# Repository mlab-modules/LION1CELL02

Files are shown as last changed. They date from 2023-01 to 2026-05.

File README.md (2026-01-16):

# LION1CELL02 - Single-cell Li-Ion BMS power supply with I2C interface 

LION1CELL02

Integrated battery management solution for 18650 Li-ion batteries. It can measure remaining energy in the battery, perform a charging cycle from a USB-C power source, and protect batteries against overvoltage or overdraining conditions.

## Features 

  * Charging, balancing, termination (temperature protected)
  * Gas-gauging (temperature compensated)
  * Over-voltage protection
  * Over-current protection
  * Under-voltage is not protected - the module is constructed to power the device until battery death 

## Connection

The module could communicate on the I2C or HDQ bus.

| Mark | signal| Description |
|---|-----|---|
|1 | PG |	|
|2 | STAT2 | |
|3 | GND |	|
|4 | CE | |
|5 | STAT1 | |
|6 | CMODE | |

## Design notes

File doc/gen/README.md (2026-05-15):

# PCB

Board size: N/AxN/A mm (N/AxN/A inches)

- This is the size of the rectangle that contains the board
- Thickness: 1.6 mm (63 mils)
- Material: FR4
- Finish: HAL
- Layers: 2
- Copper thickness: 35 µm

Solder mask: TOP / BOTTOM

- Color: Green

Silk screen: TOP / BOTTOM

- Color: White

# Important sizes

Clearance: 0.2 mm (8 mils)

Track width: N/A mm (N/A mils)

- By design rules: 0.0 mm (0 mils)

Drill: 0.6 mm (24 mils)

- Vias: N/A mm (N/A mils) [Design: 0.4 mm (16 mils)]
- Pads: 0.6 mm (24 mils)
- The above values are real drill sizes, they add 0.1 mm (4 mils) to plated holes (PTH)

Via: N/A/N/A mm (N/A/N/A mils)

- By design rules: 0.5/0.3 mm (20/12 mils)
- Micro via: yes [0.2/0.1 mm (8/4 mils)]
- Buried/blind via: yes
- Total: 0 (thru: 0 buried/blind: 0 micro: 0)

Outer Annular Ring: 0.15 mm (6 mils)

- By design rules: 0.15 mm (6 mils)

Eurocircuits class: 4A
- Using min drill 0.6 mm for an OAR of 0.15 mm

# General stats

Components count: (SMD/THT)

- Top: 31/7 (SMD + THT)
- Bottom: 51/4 (SMD + THT)

Defined tracks:

- 0.2 mm (8 mils)
- 0.3 mm (12 mils)
- 0.5 mm (20 mils)
- 1.0 mm (39 mils)

Used tracks:

Defined vias:

Used vias:

Holes (excluding vias):

- 0.65 mm (26 mils) (2)
- 1.0 mm (39 mils) (10)
- 1.6 mm (63 mils) (4)
- 3.0 mm (118 mils) (4)
- 3.2 mm (126 mils) (4)

Oval holes:

- 0.5x0.9 mm (20x35 mils) (2)
- 0.6x1.4 mm (24x55 mils) (2)
- 0.6x1.7 mm (24x67 mils) (2)

Drill tools (including vias and computing adjusts and rounding):

- 0.6 mm (24 mils) (2)
- 0.65 mm (26 mils) (2)
- 0.7 mm (28 mils) (4)
- 1.1 mm (43 mils) (10)
- 1.7 mm (67 mils) (4)
- 3.1 mm (122 mils) (4)
- 3.2 mm (126 mils) (4)

Solder paste stats:

Using a paste with 87.75 % alloy, that has an specific gravity for the alloy of 7.4 g/cm³
and 1.0 g/cm³ for the flux. This paste has an specific gravity of  4.15 g/cm³.

The stencil thickness is  0.12 mm.

| Side | Pads with paste | Area [mm²] | Paste [g] |
|---|---|---|---|
| Top | 59 | 67.12 | 0.33 |
| Bottom | 172 | 224.50 | 1.12 |
| Total  | 231 | 291.61 | 1.45 |

Note: this is just an approximation to the theoretical value. Margins of the solder mask and waste aren't computed.

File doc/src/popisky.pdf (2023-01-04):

List1

Stránka 1

1 – PG | 4 – CE | 1 – PG | 4 – CE | 1 – PG | 4 – CE
2 – STAT2 | 5 – STAT1 | 2 – STAT2 | 5 – STAT1 | 2 – STAT2 | 5 – STAT1
3 – GND | 6 – CMODE | 3 – GND | 6 – CMODE | 3 – GND | 6 – CMODE
1 – PG | 4 – CE | 1 – PG | 4 – CE | 1 – PG | 4 – CE
2 – STAT2 | 5 – STAT1 | 2 – STAT2 | 5 – STAT1 | 2 – STAT2 | 5 – STAT1
3 – GND | 6 – CMODE | 3 – GND | 6 – CMODE | 3 – GND | 6 – CMODE
1 – PG | 4 – CE | 1 – PG | 4 – CE | 1 – PG | 4 – CE
2 – STAT2 | 5 – STAT1 | 2 – STAT2 | 5 – STAT1 | 2 – STAT2 | 5 – STAT1
3 – GND | 6 – CMODE | 3 – GND | 6 – CMODE | 3 – GND | 6 – CMODE
1 – PG | 4 – CE | 1 – PG | 4 – CE | 1 – PG | 4 – CE
2 – STAT2 | 5 – STAT1 | 2 – STAT2 | 5 – STAT1 | 2 – STAT2 | 5 – STAT1
3 – GND | 6 – CMODE | 3 – GND | 6 – CMODE | 3 – GND | 6 – CMODE
1 – PG | 4 – CE | 1 – PG | 4 – CE | 1 – PG | 4 – CE
2 – STAT2 | 5 – STAT1 | 2 – STAT2 | 5 – STAT1 | 2 – STAT2 | 5 – STAT1
3 – GND | 6 – CMODE | 3 – GND | 6 – CMODE | 3 – GND | 6 – CMODE
1 – PG | 4 – CE | 1 – PG | 4 – CE | 1 – PG | 4 – CE
2 – STAT2 | 5 – STAT1 | 2 – STAT2 | 5 – STAT1 | 2 – STAT2 | 5 – STAT1
3 – GND | 6 – CMODE | 3 – GND | 6 – CMODE | 3 – GND | 6 – CMODE
1 – PG | 4 – CE | 1 – PG | 4 – CE | 1 – PG | 4 – CE
2 – STAT2 | 5 – STAT1 | 2 – STAT2 | 5 – STAT1 | 2 – STAT2 | 5 – STAT1
3 – GND | 6 – CMODE | 3 – GND | 6 – CMODE | 3 – GND | 6 – CMODE
1 – PG | 4 – CE | 1 – PG | 4 – CE | 1 – PG | 4 – CE
2 – STAT2 | 5 – STAT1 | 2 – STAT2 | 5 – STAT1 | 2 – STAT2 | 5 – STAT1
3 – GND | 6 – CMODE | 3 – GND | 6 – CMODE | 3 – GND | 6 – CMODE
1 – PG | 4 – CE | 1 – PG | 4 – CE | 1 – PG | 4 – CE
2 – STAT2 | 5 – STAT1 | 2 – STAT2 | 5 – STAT1 | 2 – STAT2 | 5 – STAT1
3 – GND | 6 – CMODE | 3 – GND | 6 – CMODE | 3 – GND | 6 – CMODE
1 – PG | 4 – CE | 1 – PG | 4 – CE | 1 – PG | 4 – CE
2 – STAT2 | 5 – STAT1 | 2 – STAT2 | 5 – STAT1 | 2 – STAT2 | 5 – STAT1
3 – GND | 6 – CMODE | 3 – GND | 6 – CMODE | 3 – GND | 6 – CMODE
1 – PG | 4 – CE | 1 – PG | 4 – CE | 1 – PG | 4 – CE
2 – STAT2 | 5 – STAT1 | 2 – STAT2 | 5 – STAT1 | 2 – STAT2 | 5 – STAT1
3 – GND | 6 – CMODE | 3 – GND | 6 – CMODE | 3 – GND | 6 – CMODE
1 – PG | 4 – CE | 1 – PG | 4 – CE | 1 – PG | 4 – CE
2 – STAT2 | 5 – STAT1 | 2 – STAT2 | 5 – STAT1 | 2 – STAT2 | 5 – STAT1
3 – GND | 6 – CMODE | 3 – GND | 6 – CMODE | 3 – GND | 6 – CMODE
1 – PG | 4 – CE | 1 – PG | 4 – CE | 1 – PG | 4 – CE
2 – STAT2 | 5 – STAT1 | 2 – STAT2 | 5 – STAT1 | 2 – STAT2 | 5 – STAT1
3 – GND | 6 – CMODE | 3 – GND | 6 – CMODE | 3 – GND | 6 – CMODE

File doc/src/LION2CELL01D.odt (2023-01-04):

Modul obsluhující dva sériově zapojené li-on články 18650

Jan Chroust

## Modul je osazen obvodem pro zajištění nabíjení dvou sériově zapojených li-on článků. Samozřejmostí je moderní obvod pro měření zbývající energie a celkové monitorování článků. Výstupem je I2C sběrnice. Článek je ošetřen proti případnému poškození přepětím.

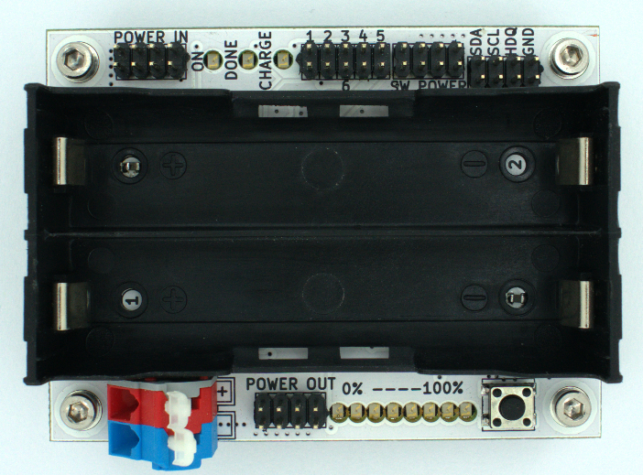
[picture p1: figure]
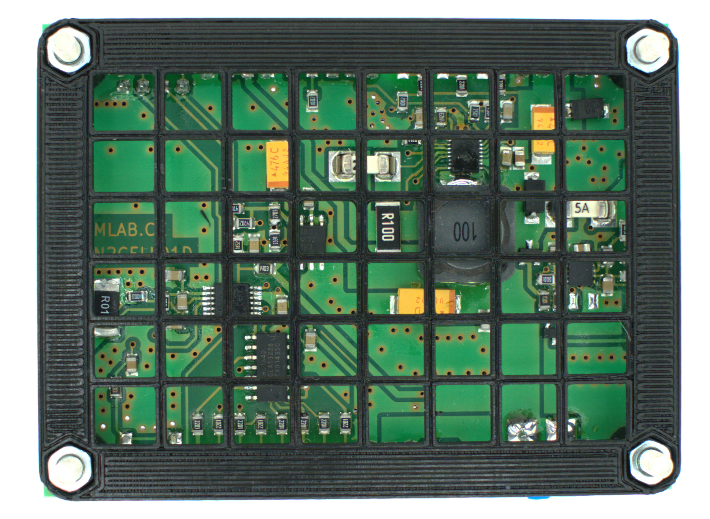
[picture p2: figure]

# Technické parametry

Parametr | Hodnota | Poznámka
Napájení | 12 V@2A | Nabíjecí proud je z výroby nastaven na cca 1,3A
Pouzdro na články | 2x18650
Rozhraní | I2C, HDQ
Integrované obvod: | BQ24103 | Nabíjení
| BQ34Z100 | Měření článku
Rozměry | 80.77 x 60.45 x 16 mm | Výška nad základní deskou

# Popis konstrukce

Modul obsahuje tři samostatné funkční celky – Dobíjecí elektroniku, měření parametrů a balanční a ochranný obvod. Většina z nich pracuje stále i když modul není využíván. Důsledkem je, že modul je nutné pravidelně nabíjet (alespoň jednou za půl roku), aby byly akumulátory udržovány v provozním rozsahu napětí.

## Nastavení děliče u BQ34Z100 pro měření napětí

Dělič pro měření napětí je tvořen odpory R23 a R24. Hodnota napětí na pinu BAT nesmí přesáhnout 900 mV, proto se hodnota odporu vypočítá následujícím vzorcem:

{R} rsub {24} =16500 Ω ( {V} rsub {in max} -900mV)/900mV

Výsledkem je pro dva články 137,5 kΩ, ale z důvodu lepší dostupnosti byl zvolen obvod R24 140kΩ. R23 16k5.

Výpočet hodnoty dělícího poměru v mV, který se zapisuje do nastavení obvodu se dopočítá tímto vzorcem:

Poměr= {1000} over {{R} rsub {23}} *( {R} rsub {23} + {R} rsub {24} )

Po vložení hodnot:

Poměr= {1000} over {16,5} *(16,5+140)

Výsledná hodnota poměru:

Poměr=9484 mV

Po převod na HEX (tato hodnota se vkládá):

Poměr=250C

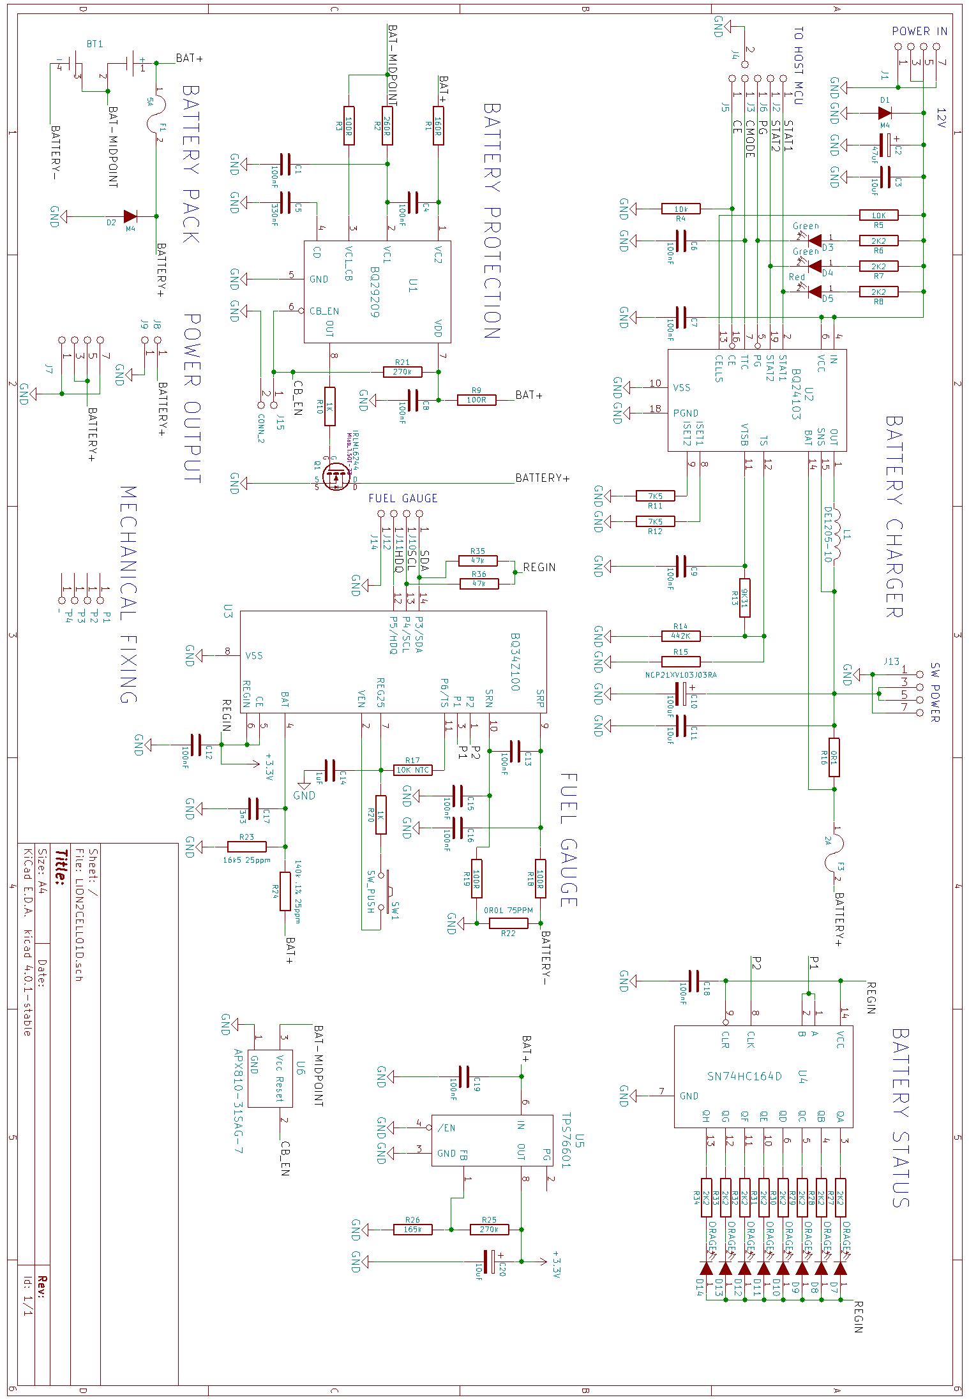
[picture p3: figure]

# Schéma

# Osazení a oživení

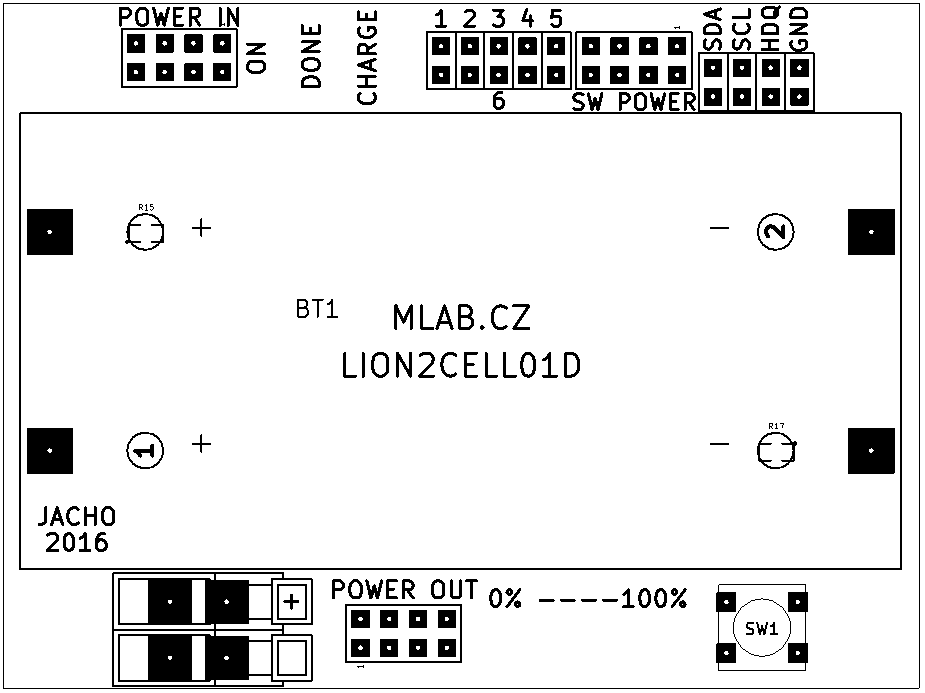
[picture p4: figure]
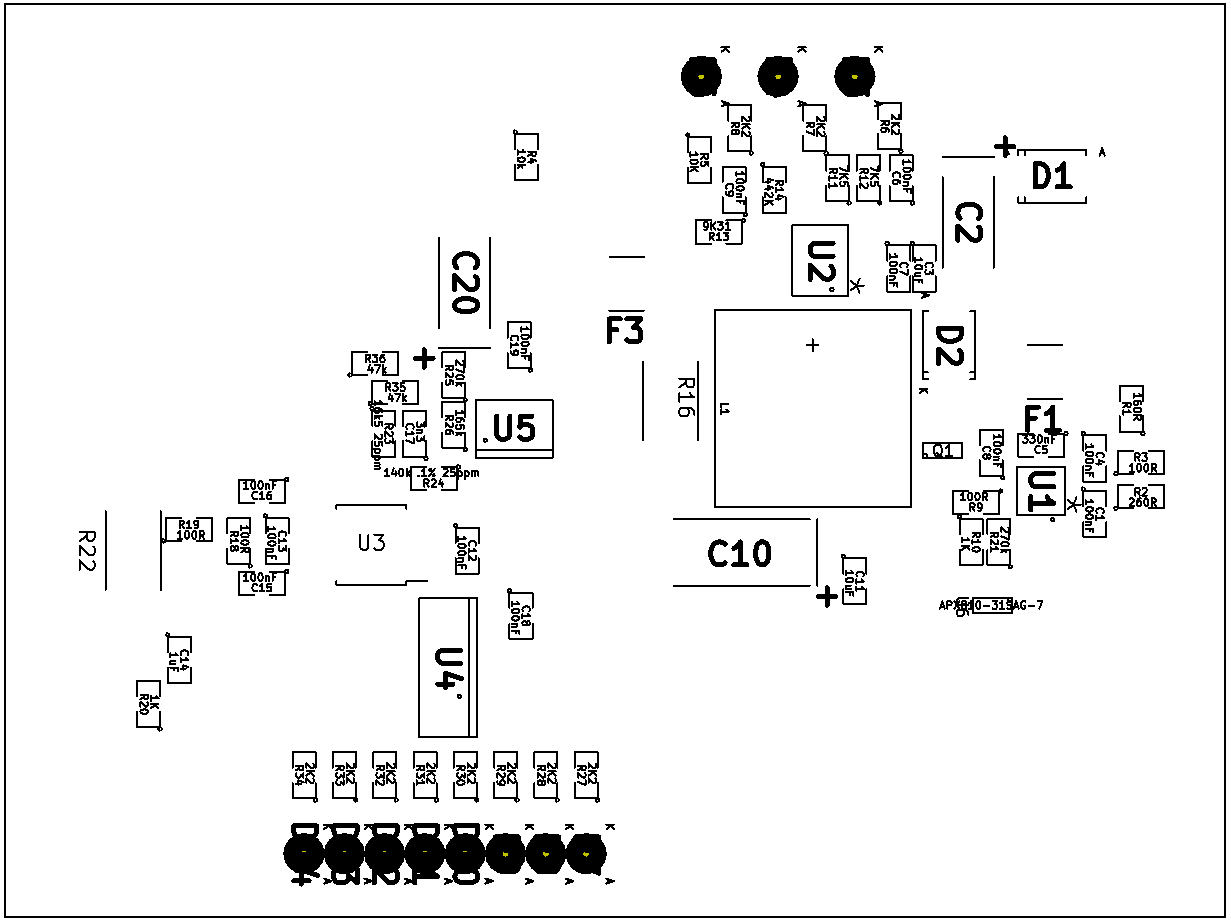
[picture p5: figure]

### Osazení

Označení | Typ | Pouzdro | Počet
BT1 | 2x18650_LION-RESCUE-LION2CELL01C | 2LION | 1
C1,C4,C6,C7,C8,C9,C12,C13,C15,C16,C18,C19 | 100nF | SMD-0805 | 12
C2 | 47uF | TantalC_SizeC_Reflow | 1
C3,C11 | 10uF | SMD-0805 | 2
C5 | 330nF | SMD-0805 | 1
C14 | 1uF | SMD-0805 | 1
C17 | 3n3 | SMD-0805 | 1
D1,D2 | M4 | SMA_Standard | 2
J1,J7,J13 | JUMP_4X2 | Straight_2x04 | 3
J2,J3,J5,J6,J10,J11,J12,J14 | JUMP_2x1 | Straight_1x02 | 8
J4 | JUMP2_2x1 | Straight_1x02 | 1
J8,J9 | CONN1_1 | WAGO256 | 2
L1 | DE1205-10 | DE1205-10 | 1
P1,P2,P3,P4 | _ | MountingHole_3mm | 4
Q1 | IRLML6244 | SOT-23 | 1
R1 | 160R | SMD-0805 | 1
R2 | 260R | SMD-0805 | 1
R3,R9,R18,R19 | 100R | SMD-0805 | 4
R4 | 10k | SMD-0805 | 1
R5 | 10K | SMD-0805 | 1
R6,R7,R8,R27,R28,R29,R30,R31,R32,R33,R34 | 2K2 | SMD-0805 | 11
R10,R20 | 1K | SMD-0805 | 2
R11,R12 | 7K5 | SMD-0805 | 2
R13 | 9K31 | SMD-0805 | 1
R14 | 442K | SMD-0805 | 1
R15 | NCP21XV103J03RA | SMD-0805 | 1
R16 | 0R1 | R_2512 | 1
R17 | 10K NTC | SMD-0805 | 1
R21,R25 | 270k | SMD-0805 | 2
R23 | 16k5 25ppm | SMD-0805 | 1
R24 | 140k .1% 25ppm | SMD-0805 | 1
R26 | 165k | SMD-0805 | 1
U4 | SN74HC164D | SO-14 | 1
SW1 | SW_PUSH | SW_PUSH_SMALL | 1
U3 | BQ34Z100 | TSSOP-14_4.4x5mm_Pitch0.65mm | 1
U1 | BQ29209 | VSON-8 | 1
C10 | 100uF | TantalC_SizeD_Reflow | 1
U2 | BQ24103 | VQFN-20 | 1
F1 | 5A | Drzak_2410 | 1
F3 | 2A | Drzak_2410 | 1
D7,D8,D9,D10,D11,D12,D13,D14 | ORAGE | LED_1206 | 8
D3,D4 | Green | LED_1206 | 2
D5 | Red | LED_1206 | 1
J15 | CONN_2 | SMD_1_2x2 | 1
C20 | 10uF | TantalC_SizeC_Reflow | 1
U5 | TPS76601 | SO-8 | 1
R35,R36 | 47k | SMD-0805 | 2
U6 | APX810-31SAG-7 | SOT-23 | 1
R22 | 0R01 75PPM | SMD-2512 | 1
Šrouby | M3x16 DIN 912 | | 4
3D tištěná podložka | | | 1

Při osazování svorkovnice J8/9, které jsou spojené do jednoho dílu je nutné uříznout přečnívající čudliky z červené části. Jinak se svorkovnice odklání od bateriového pouzdra.

3D tištěná podložka má po tisku zaslepené otvory technologickým mostem. Ten je potřeba po tisku odvrtat vrtákem o průměru 3mm. Odvrtávání je nelepší provést akušroubovákem nebo vrtačkou přepnutou na zpětný běh (tj. Opačně než by se normálně vrtákem vrtalo), tím je dosaženo přesnějšího otvoru v mostu.

### Oživení

Nejprve je dobré zkontrolovat PCB, zda je dobře zapájené. Následně se mohou vložit baterie. Je potřeba dodržet pořadí vyznačené pod pouzdrem. Nejprve se vkládá baterie do pozice 1 a pak teprve do pozice 2. Prohození pořadí může způsobit, že se modul nebude chovat správně. Po vložení posledního článku se rozsvítí oranžové LED pro diagnostiku zbývající energie článků.

Dále je vhodné vyzkoušet, zda je funkční funkce nabíjení.

Po zapojení 12V adaptéru by se měla rozsvítit zelená LED detekující připojení napájení. Následně by se měla rozsvítit červená LED indikující, že modul nabíjí. Po ukončení nabíjení druhá zelená LED indikující plně nabité akumulátory.

Program setguage2cell.py (https://github.com/mlab-modules/LION2CELL01/blob/LION2CELL01D/sw/setguage2cell.py) pro nahrání parametrů do obvodu pro měření energie článků se nachází ve složce sw (https://github.com/mlab-modules/LION2CELL01/tree/LION2CELL01D/sw) repozitáře modulu. Program používá knihovnu PyMLAB (https://github.com/MLAB-project/pymlab), kterou je potřeba mít nainstalovánu. Potom je možné modul nastavit příkazem

$ setguage2cell.py (https://github.com/mlab-modules/LION2CELL01/blob/LION2CELL01D/sw/setguage2cell.py) 8 NCR18650B

Nejsnadnější použití je pomocí modulu USBI2C01A (https://github.com/MLAB-project/Modules/tree/master/comm_serial/USBI2C01A).

Po nahrání parametrů pomocí setguage2cell.py (https://github.com/mlab-modules/LION2CELL01/blob/LION2CELL01D/sw/setguage2cell.py) je potřeba odpojit články a připojit je zpět v již popsaném pořadí. Toho lze nejsnadněji dosáhnout vražením nastříhaných plastových pásků mezi akumulátor a kontakty pouzdra. (Nastavení bez vložených akumulátorů nefunguje.)

Pro ověření, že je modul dobře zkonfigurován, slouží druhý program guage.py (https://github.com/mlab-modules/LION2CELL01/blob/LION2CELL01D/sw/guage.py), který vyčítá naměřená data.

Parametry, které se nahrávají do obvodu odpovídají článku 18650 od firmy Panasonic typ NCR18650B a nebo volitelně INR18650MJ1. V případě užití jiných akumulátorů, je potřeba nahrávané parametry změnit ve zdrojovém kódu setguage2cell.py (https://github.com/mlab-modules/LION2CELL01/blob/LION2CELL01D/sw/setguage2cell.py)! Jinak modul sice bude fungovat, ale udávaná data o kapacitě článků nebudou spolehlivá. Měření napětí na článcích, protékajícího proudu a teploty článku bude v pořádku.

Po vložení článků je potřeba provést minimálně jeden vybíjecí a nabíjecí cyklus, aby byly hodnoty zbývající energie přesnější. Čím déle budou články vloženy v modulu, tím budou měřené hodnoty přesnější. Pokud dojde k vyndání článků, tak měřící obvod resetuje měřené parametry a zpřesňování bude probíhat od začátku.

Modul je vybaven balančním obvodem, který vyrovnává napětí na obou článcích na stejnou hodnotu. Vyrovnávání se provádí tak, že jeden z článků je vybíjen. Tento vybíjecí proud měřící obvod zaznamenává. Pohybuje se řádově na hodnotě 10mA.

LION2CELL01D MLAB

LION2CELL01D / 2016-04-05 / jacho/ http://www.mlab.cz 7 / 7

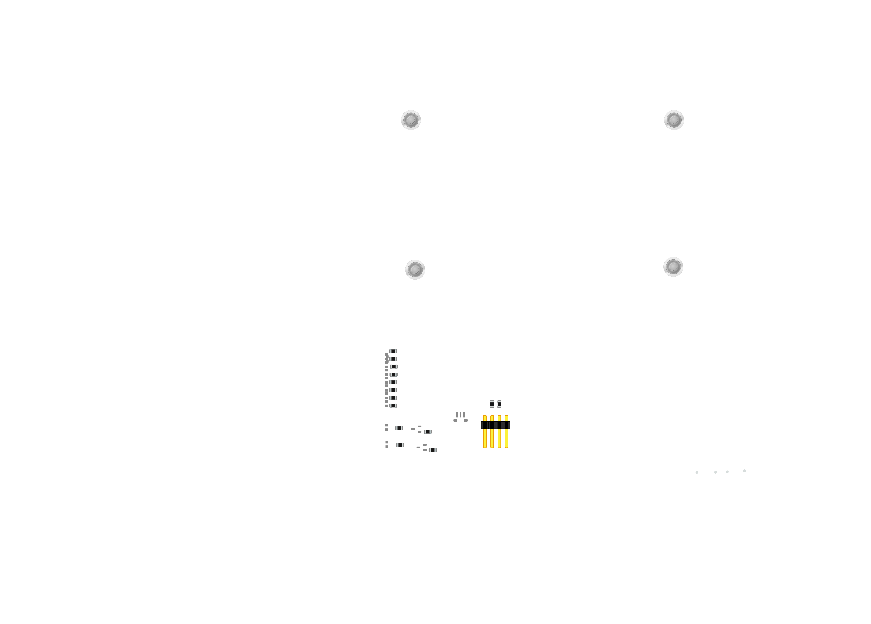
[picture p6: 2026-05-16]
doc/gen/img/LION1CELL02-top.png

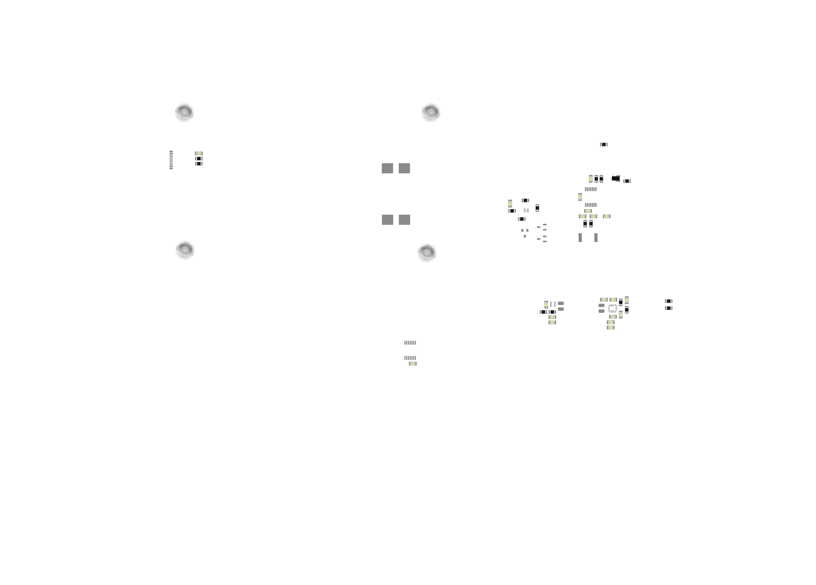
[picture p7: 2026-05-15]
doc/gen/img/LION1CELL02-bottom.png

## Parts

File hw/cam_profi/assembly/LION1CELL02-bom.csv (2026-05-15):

Component | Description | Part | References | Value | Footprint | Quantity Per PCB | Datasheet | ust_id | mfpn | mpn | sim.pins | sim.device | sim.type | i2c | height | mouser part number | mouser price/stock | manufacturer_name | manufacturer_part_number
1 | Single-cell battery | 2xBATT | BT1 | BATT | BAT_BK-18650-PC4 | 1 |  | 5c70984412875079b91f87e9
2 | Unpolarized capacitor, small symbol | C_Small | C3 | 1n | C_0805_2012Metric | 1 |  | 5c70984712875079b91f8b45 | C0805 1u | C0805 1u
3 | Unpolarized capacitor, small symbol | C_Small | C12 | 3n3 | C_0805_2012Metric | 1 |  | 5c70984712875079b91f8b47
4 | Unpolarized capacitor, small symbol | C_Small | C5 | 47n | C_0805_2012Metric | 1 |  | 65482046462c6d9e72056b98
5 | Unpolarized capacitor, small symbol | C_Small | C1C2C4C11C14C18C19 | 100n | C_0805_2012Metric | 7 |  | 5c70984712875079b91f8b4c
6 | Unpolarized capacitor, small symbol | C_Small | C8C13 | 1u | C_0805_2012Metric | 2 |  | 5c70984712875079b91f8b50
7 | Unpolarized capacitor, small symbol | C_Small | C9 | 4u7 | C_0805_2012Metric | 1 |  | 5c70984712875079b91f8b52
8 | Unpolarized capacitor, small symbol | C_Small | C7C10C17 | 10u | C_0805_2012Metric | 3 |  | 5c70984712875079b91f8b53
9 | Unpolarized capacitor, small symbol | C_Small | C6C15 | 22u | C_0805_2012Metric | 2 |  | 650b58f1462c6d9e7205463b
10 | Unpolarized capacitor, small symbol | C_Small | C16 | 47u | C_0805_2012Metric | 1 |  | 5c70984812875079b91f8bbf
11 | Dual diode, common cathode on pin 3 | D_Dual_CommonCathode_AAK | D11 | BAT54C | SOT-23 | 1
12 | Light emitting diode, small symbol | LED_Small | D5D6D7D8D10 | GREEN | SMD_LED_RIGHT_KINGBRIGHT_1605 | 5 |  | 65481f0c462c6d9e72056b3d |  |  | 1=K 2=A
13 | Light emitting diode, small symbol | LED_Small | D3D4D9 | ORANGE | SMD_LED_RIGHT_KINGBRIGHT_1605 | 3 |  | 65481fdd462c6d9e72056b6a |  |  | 1=K 2=A
14 | Light emitting diode, small symbol | LED_Small | D1D2 | RED | SMD_LED_RIGHT_KINGBRIGHT_1605 | 2 |  | 65481f96462c6d9e72056b54 |  |  | 1=K 2=A
15 | Fuse | Fuse | F1F2 | Fuse | Fuseholder_Littelfuse_Nano2_154x | 2 |  | 5c70984512875079b91f88d8
16 | 1x04 2.54 mm pitch header | HEADER_1x04 | J3 | HEADER_1x04 | PinHeader_1x04_P2.54mm_Horizontal | 1
17 | 2x03 2.54 mm pitch header | HEADER_2x03 | J2 | HEADER_2x03 | PinHeader_2x03_P2.54mm_Vertical | 1
18 | USB 2.0-only Type-C Receptacle connector | USBC_USB4105-GF-A | J1 | USBC_USB4105-GF-A | USBC GCT_USB4105-GF-A | 1 |  | 5fa0f94612875025b397795e | USB4105-GF-A | USB4105-GF-A
19 | Inductor | L | L1L2 | 1uH - DFE252012P-1R0M=P2 | L_1008_2520Metric | 2 |  | 650b5977462c6d9e72054656
20 | N-MOSFET transistor, gate/drain/source | Q_NMOS_GDS | Q4Q5 | AO3400A | SOT-23-3 | 2
21 | PNP transistor, base/emitter/collector | Q_PNP_BEC | Q2Q3 | BC807-25 | SOT-23-3 | 2 |  | 5c70984712875079b91f8aeb |  |  | 1=C 2=B 3=E | NPN | GUMMELPOON
22 | P-MOSFET transistor, gate/source/drain | Q_PMOS_GSD | Q1 | BSS83P | SOT-23 | 1 |  | 5c70984712875079b91f8ae6
23 | Resistor, small symbol | R_Small | R17R18R19R20R24 | 68R | R_0805_2012Metric | 5 |  | 5c70984512875079b91f8975
24 | Resistor, small symbol | R_Small | R1R4 | 100R | R_0805_2012Metric | 2 |  | 5c70984512875079b91f8977
25 | Resistor, small symbol | R_Small | R11R13R14R15R16R23 | 270R | R_0805_2012Metric | 6 |  | 5c70984512875079b91f8983
26 | Resistor, small symbol | R_Small | R25 | 330 | R_0805_2012Metric | 1
27 | Resistor, small symbol | R_Small | R10 | 510R | R_0805_2012Metric | 1 |  | 5c70984512875079b91f8988
28 | Resistor, small symbol | R_Small | R12R21R22R28R29 | 1k | R_0805_2012Metric | 5 |  | 5c70984512875079b91f898c
29 | Resistor, small symbol | R_Small | R27 | 2k2 | R_0805_2012Metric | 1
30 | Resistor, small symbol | R_Small | R7 | 2k4 | R_0805_2012Metric | 1 |  | 5c70984612875079b91f8991
31 | Resistor, small symbol | R_Small | R30R31 | 4k7 | R_0805_2012Metric | 2 |  | 5c70984512875079b91f898c
32 | Resistor, small symbol | R_Small | R2R3R5 | 5k1 | R_0805_2012Metric | 3 |  | 5fa0fc3e12875025b3977997
33 | Resistor, small symbol | R_Small | R6 | 33k | R_0805_2012Metric | 1 |  | 5c70984712875079b91f8a8a
34 | Resistor, small symbol | R_Small | R9 | 91k | R_0805_2012Metric | 1 |  | 5c70984712875079b91f8a95
35 | Resistor, small symbol | R_Small | R8 | 511k | R_0805_2012Metric | 1 |  | 650b5a43462c6d9e7205468e
36 | Resistor, small symbol | R_Small | R26 | 0R01 75PPM | R_2512_6332Metric | 1 |  | 5c70984712875079b91f8abf
37 | Push button switch, generic, two pins | SW_Push_shield | SW1 | SKRTLAE010 | SKRT | 1
38 | Temperature dependent resistor | Thermistor | TH1 | 10k NTC | R_0805_2012Metric | 1 |  | 5c70984712875079b91f8ac5
39 | Temperature dependent resistor, negative temperature coefficient | Thermistor_NTC | TH2 | 10k NTC | R_0805_2012Metric | 1 |  | 5c70984712875079b91f8ac5
40 | BQ25628E I2C Controlled 1-Cell, 2-A, Maximum 18-V Input, Buck Battery Charger withNVDC Power Path Management | BQ25628E | U2 | BQ25628E | Texas_S-WQFN-HR-18 | 1 | https://www.ti.com/lit/ds/symlink/bq25628e.pdf | 65481a71462c6d9e72056aa4 |  |  |  |  |  | 0x6B
41 | Voltage and Current Protection for Single-Cell Li-Ion and Li-Polymer Batteries | BQ297xy | U5 | BQ29700DSER | WSON-6_1.5x1.5mm_P0.5mm | 1 | http://www.ti.com/lit/ds/symlink/bq2970.pdf
42 |  | BQ34Z100 | U1 | BQ34Z100 | TSSOP-14_4.4x5mm_Pitch0.65mm | 1 | https://www.ti.com/lit/ds/symlink/bq34z100-g1.pdf | 5c70984612875079b91f89c3 |  |  |  |  |  | 0xAA | 1,2
43 |  | SN74HC164D | U4 | SN74HC164P | TSSOP-14_4.4x5mm_P0.65mm | 1 | https://www.ti.com/lit/ds/symlink/sn74hc164.pdf | 6559399f95a79cc5ac40a0a6
44 | Switching Voltage Regulators 1.5-A output current, high power density buck-boost converter | TPS631000DRLR | U3 | TPS631000DRLR | SOT-583-8 | 1 | https://www.ti.com/lit/ds/symlink/tps631000.pdf?ts=1652152702265 | 63de5ae4ae0b2d5aa05e2714 |  |  |  |  |  |  | 0.5 | 595-TPS631000DRLR | https://www.mouser.co.uk/ProductDetail/Texas-Instruments/TPS631000DRLR?qs=rSMjJ%252B1ewcRYwoN2deTeNA%3D%3D | Texas Instruments | TPS631000DRLR

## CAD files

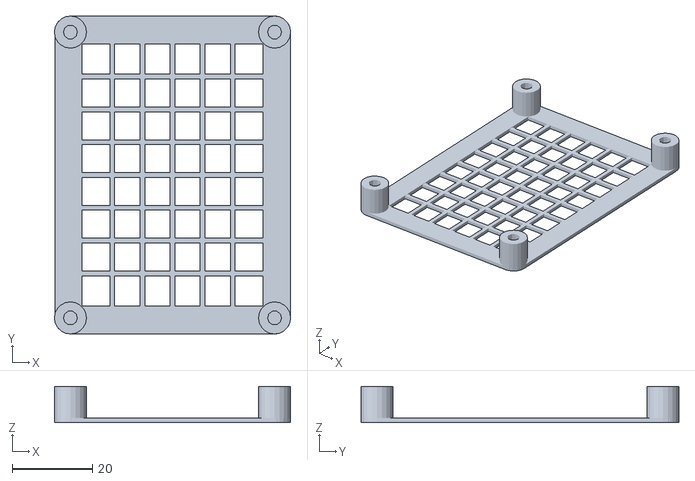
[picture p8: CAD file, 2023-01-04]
cad/6x8MLAB_frame.stl
58.8 x 79.1 x 9.00

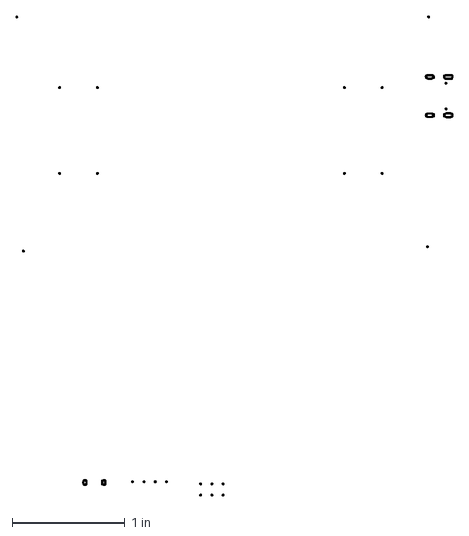
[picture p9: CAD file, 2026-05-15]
doc/gen/dxf/LION1CELL02-User_Drawings.dxf
3.87 x 4.25 in

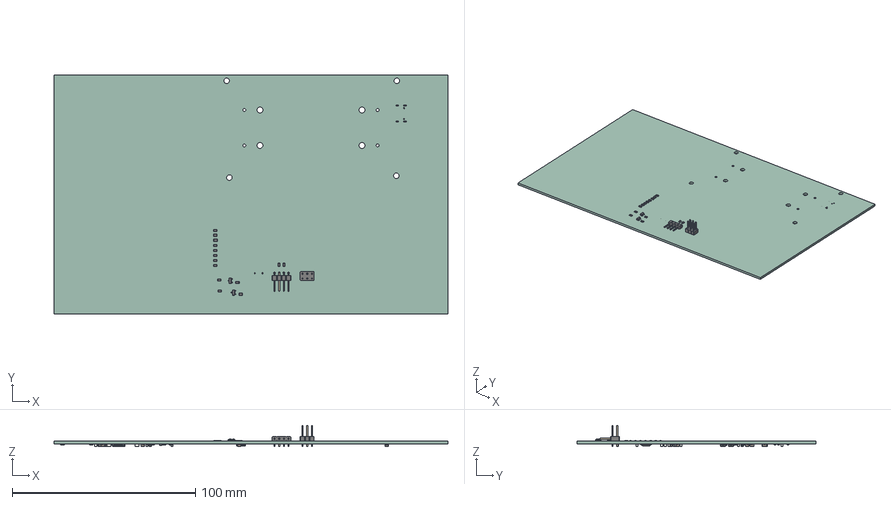
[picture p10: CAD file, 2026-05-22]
doc/gen/LION1CELL02.step
214.7 x 130.0 x 11.5 mm
SOT-23-3 x 4
R_0805_2012Metric x 32
PinHeader_2x03_P2.54mm_Vertical
PinHeader_1x04_P2.54mm_Horizontal
L_1008_2520Metric x 2
SOT-583-8
R_2512_6332Metric
C_0805_2012Metric x 18
Texas_S-PWQFN-N20
SOT-23
TSSOP-14_4.4x5mm_P0.65mm
WSON-6_1.5x1.5mm_P0.5mm
kibot_98wqftvz_PCB

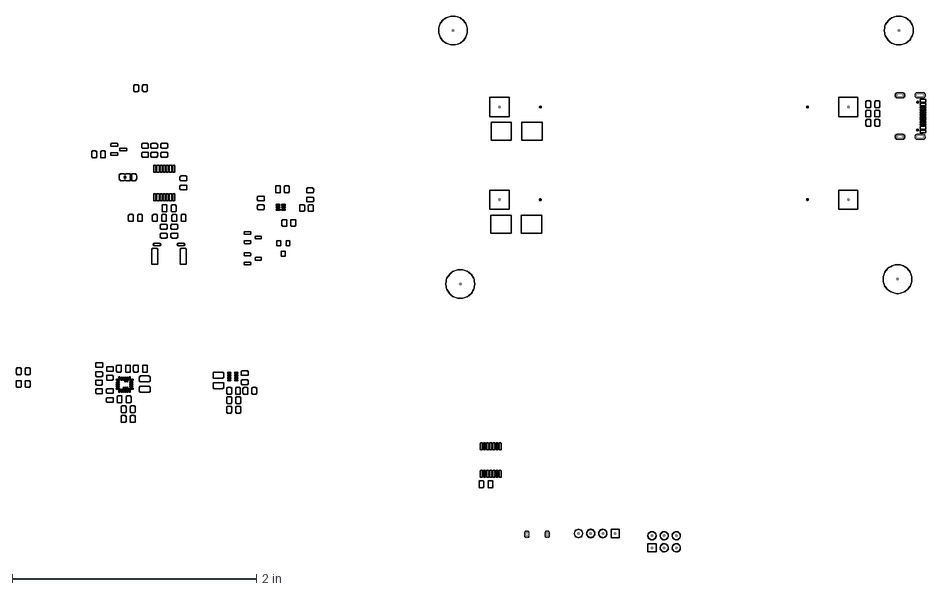
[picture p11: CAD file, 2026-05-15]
doc/gen/dxf/LION1CELL02-B_Cu.dxf
7.45 x 4.39 in

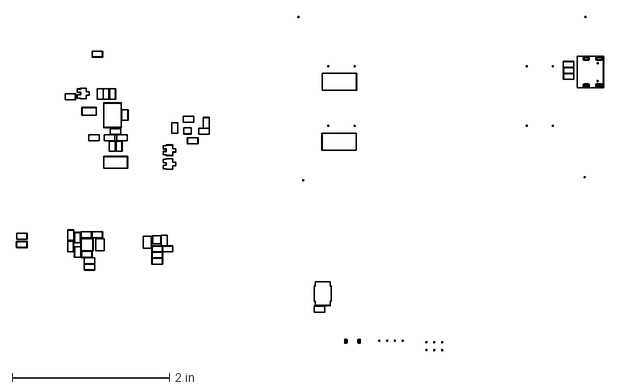
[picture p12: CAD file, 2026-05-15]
doc/gen/dxf/LION1CELL02-B_Courtyard.dxf
7.47 x 4.25 in

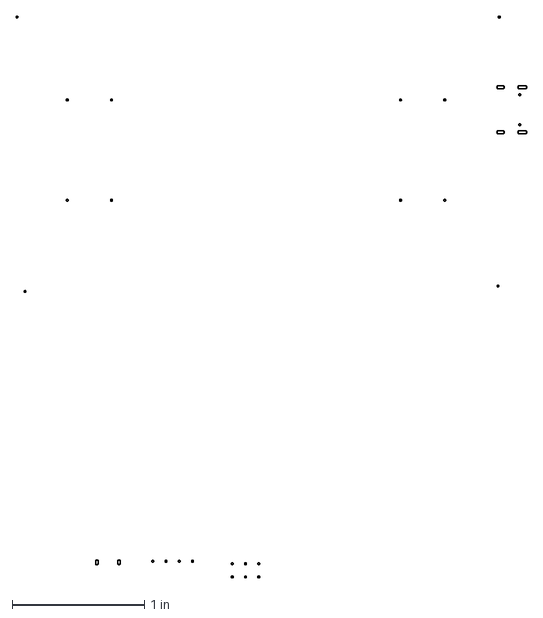
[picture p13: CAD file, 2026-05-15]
doc/gen/dxf/LION1CELL02-B_Adhesive.dxf
3.87 x 4.25 in

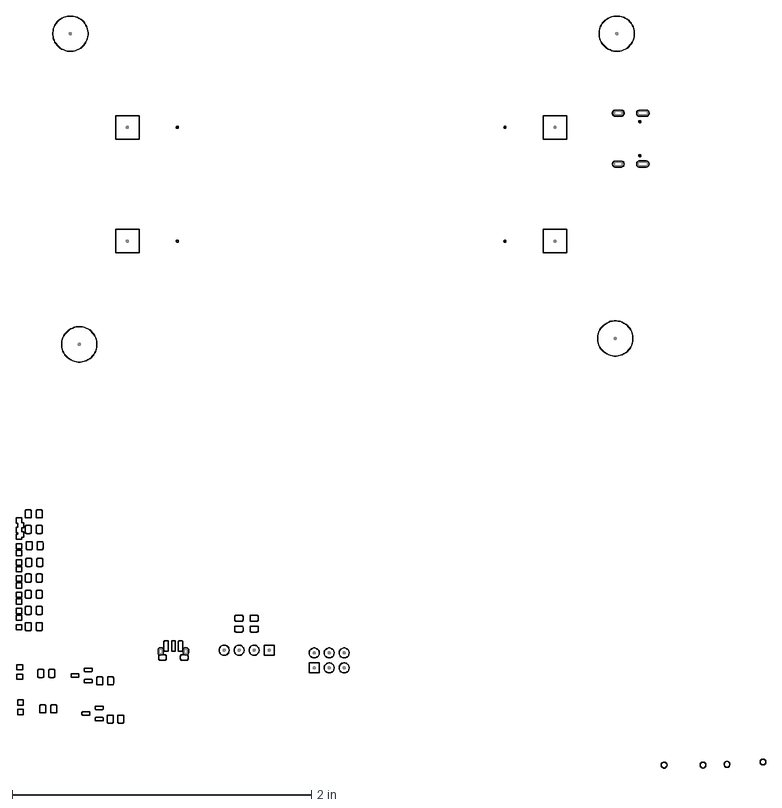
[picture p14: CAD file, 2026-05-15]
doc/gen/dxf/LION1CELL02-F_Cu.dxf
5.01 x 5.03 in

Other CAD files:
cad/src/6x8MLAB_frame.scad
doc/gen/dxf/LION1CELL02-B_Fab.dxf
doc/gen/dxf/LION1CELL02-B_Mask.dxf
doc/gen/dxf/LION1CELL02-B_Paste.dxf
doc/gen/dxf/LION1CELL02-B_Silkscreen.dxf
doc/gen/dxf/LION1CELL02-F_Courtyard.dxf
doc/gen/dxf/LION1CELL02-F_Fab.dxf
doc/gen/dxf/LION1CELL02-F_Mask.dxf
doc/gen/dxf/LION1CELL02-F_Paste.dxf
doc/gen/dxf/LION1CELL02-F_Silkscreen.dxf
doc/gen/dxf/LION2CELL01D-F_Courtyard.dxf
doc/gen/dxf/LION2CELL01D-F_Fab.dxf
doc/gen/dxf/LION2CELL01D-Margin.dxf
doc/gen/dxf/LION2CELL01D-User_Drawings.dxf
doc/gen/dxf/LION2CELL01D-User_Eco1.dxf
doc/gen/dxf/LION2CELL01D-User_Eco2.dxf

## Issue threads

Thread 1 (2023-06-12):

Output voltage converter

kaklik, 2023-06-12:
Vypadá to že pro aktualizovanou verzi modulu je vhodný měnič [TPS631000](https://www.ti.com/product/TPS631000).

_Originally posted by @kaklik in https://github.com/mlab-modules/LION1CELL01/issues/1#issuecomment-1365806545_

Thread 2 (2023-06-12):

Add USB-C connector for charging

kaklik, 2023-06-12:
Moderní řešení jak něco nabíjet je připojit zařízení přes USB-C. Tudíž by se hodil USB-C nabíjecí konektor.

To ale znamená vyměnit aktuální dobíjecí obvod za nějaký který umí [power delivery](https://www.alza.cz/usb-power-delivery) pro nabíjení lion-akumulátorů.

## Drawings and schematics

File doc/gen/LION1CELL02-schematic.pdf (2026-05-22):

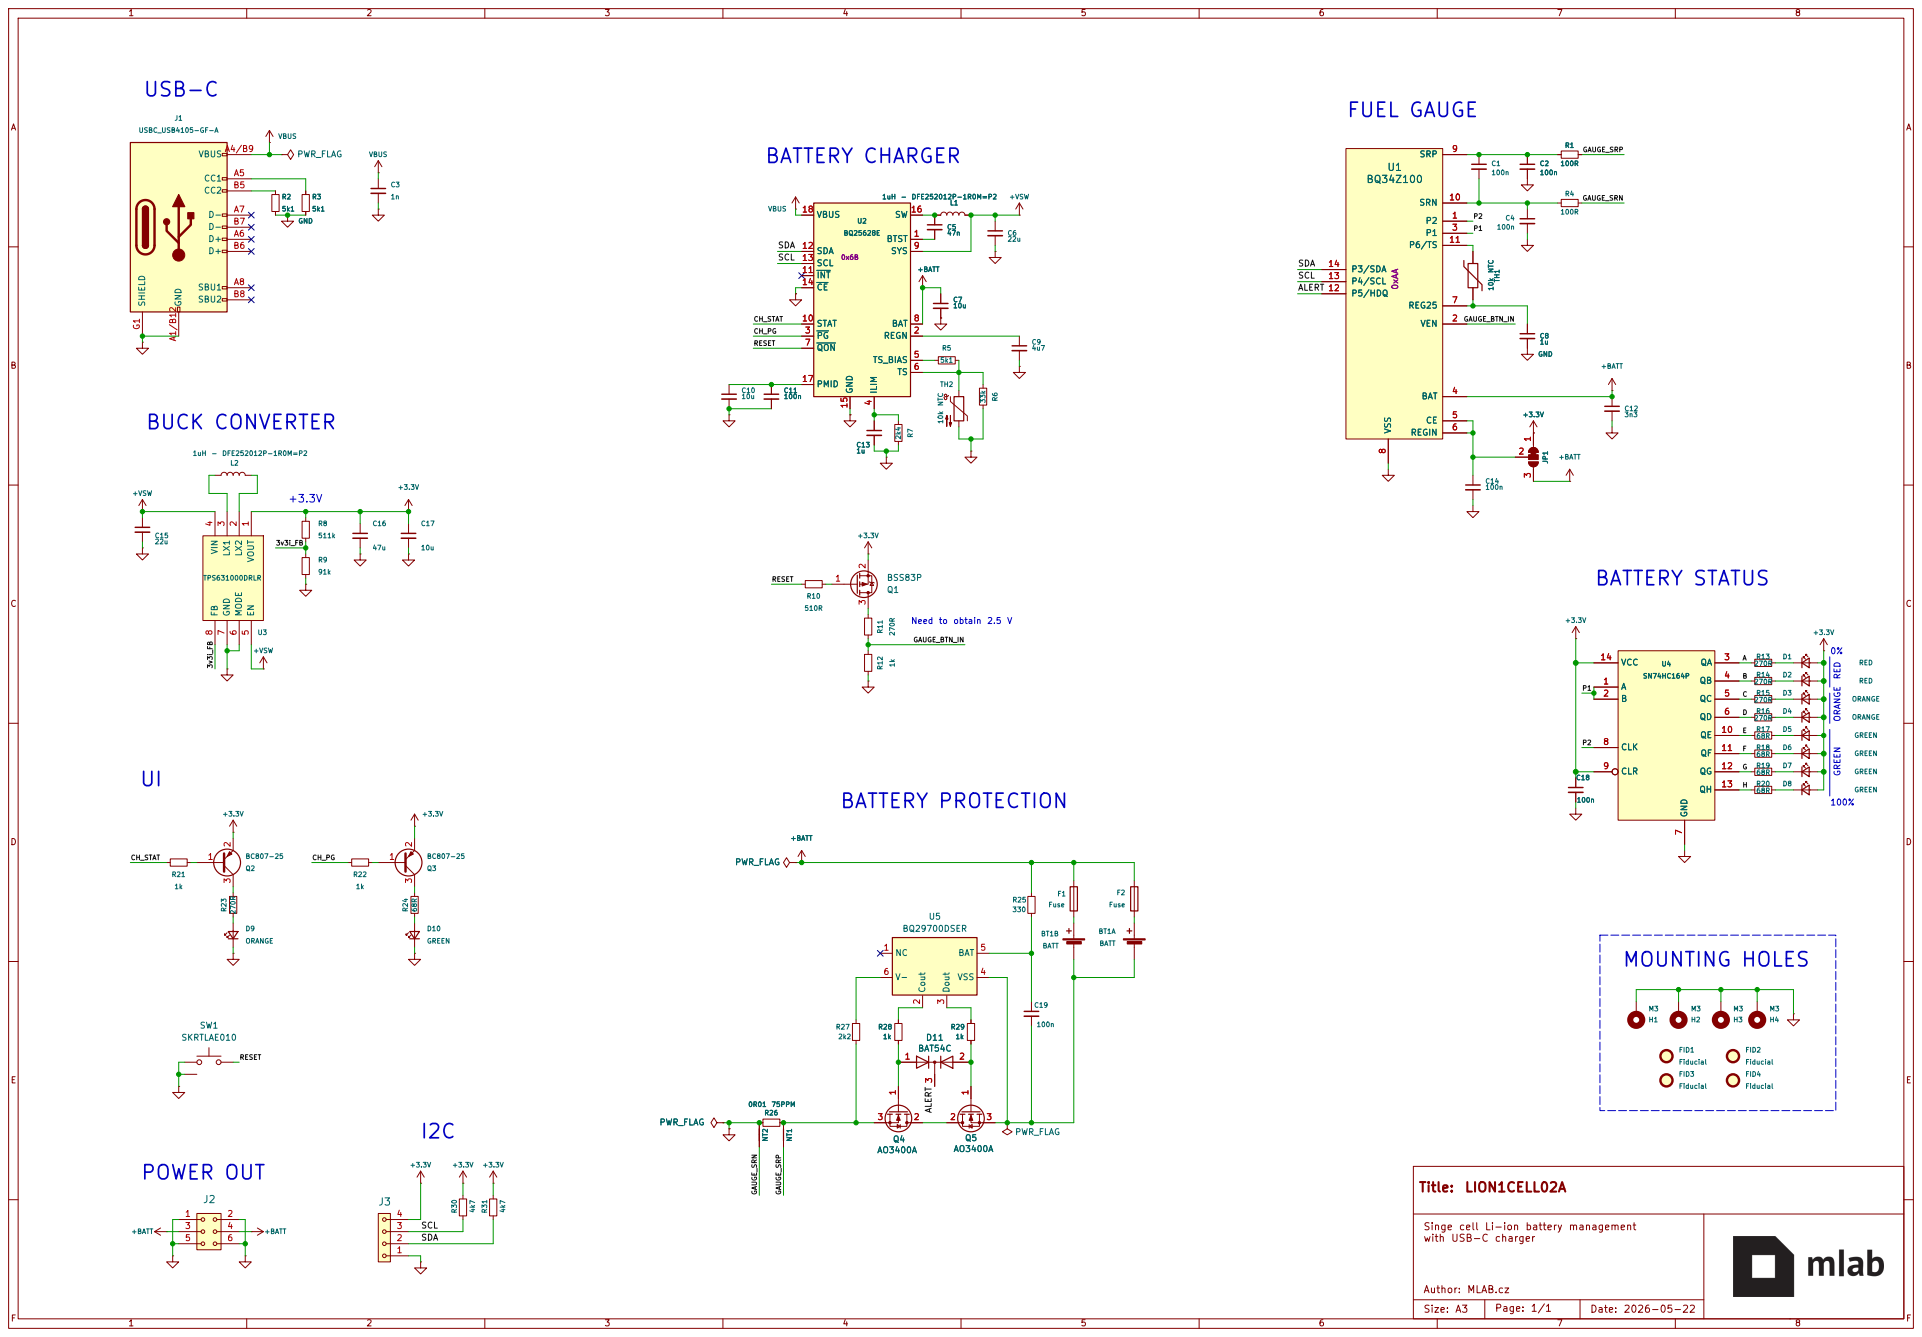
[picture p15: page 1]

Need to obtain 2.5 V BATTERY CHARGER

Singe cell Li-ion battery management

Size: A3 | Page: 1/1 | Date: 2026-05-22

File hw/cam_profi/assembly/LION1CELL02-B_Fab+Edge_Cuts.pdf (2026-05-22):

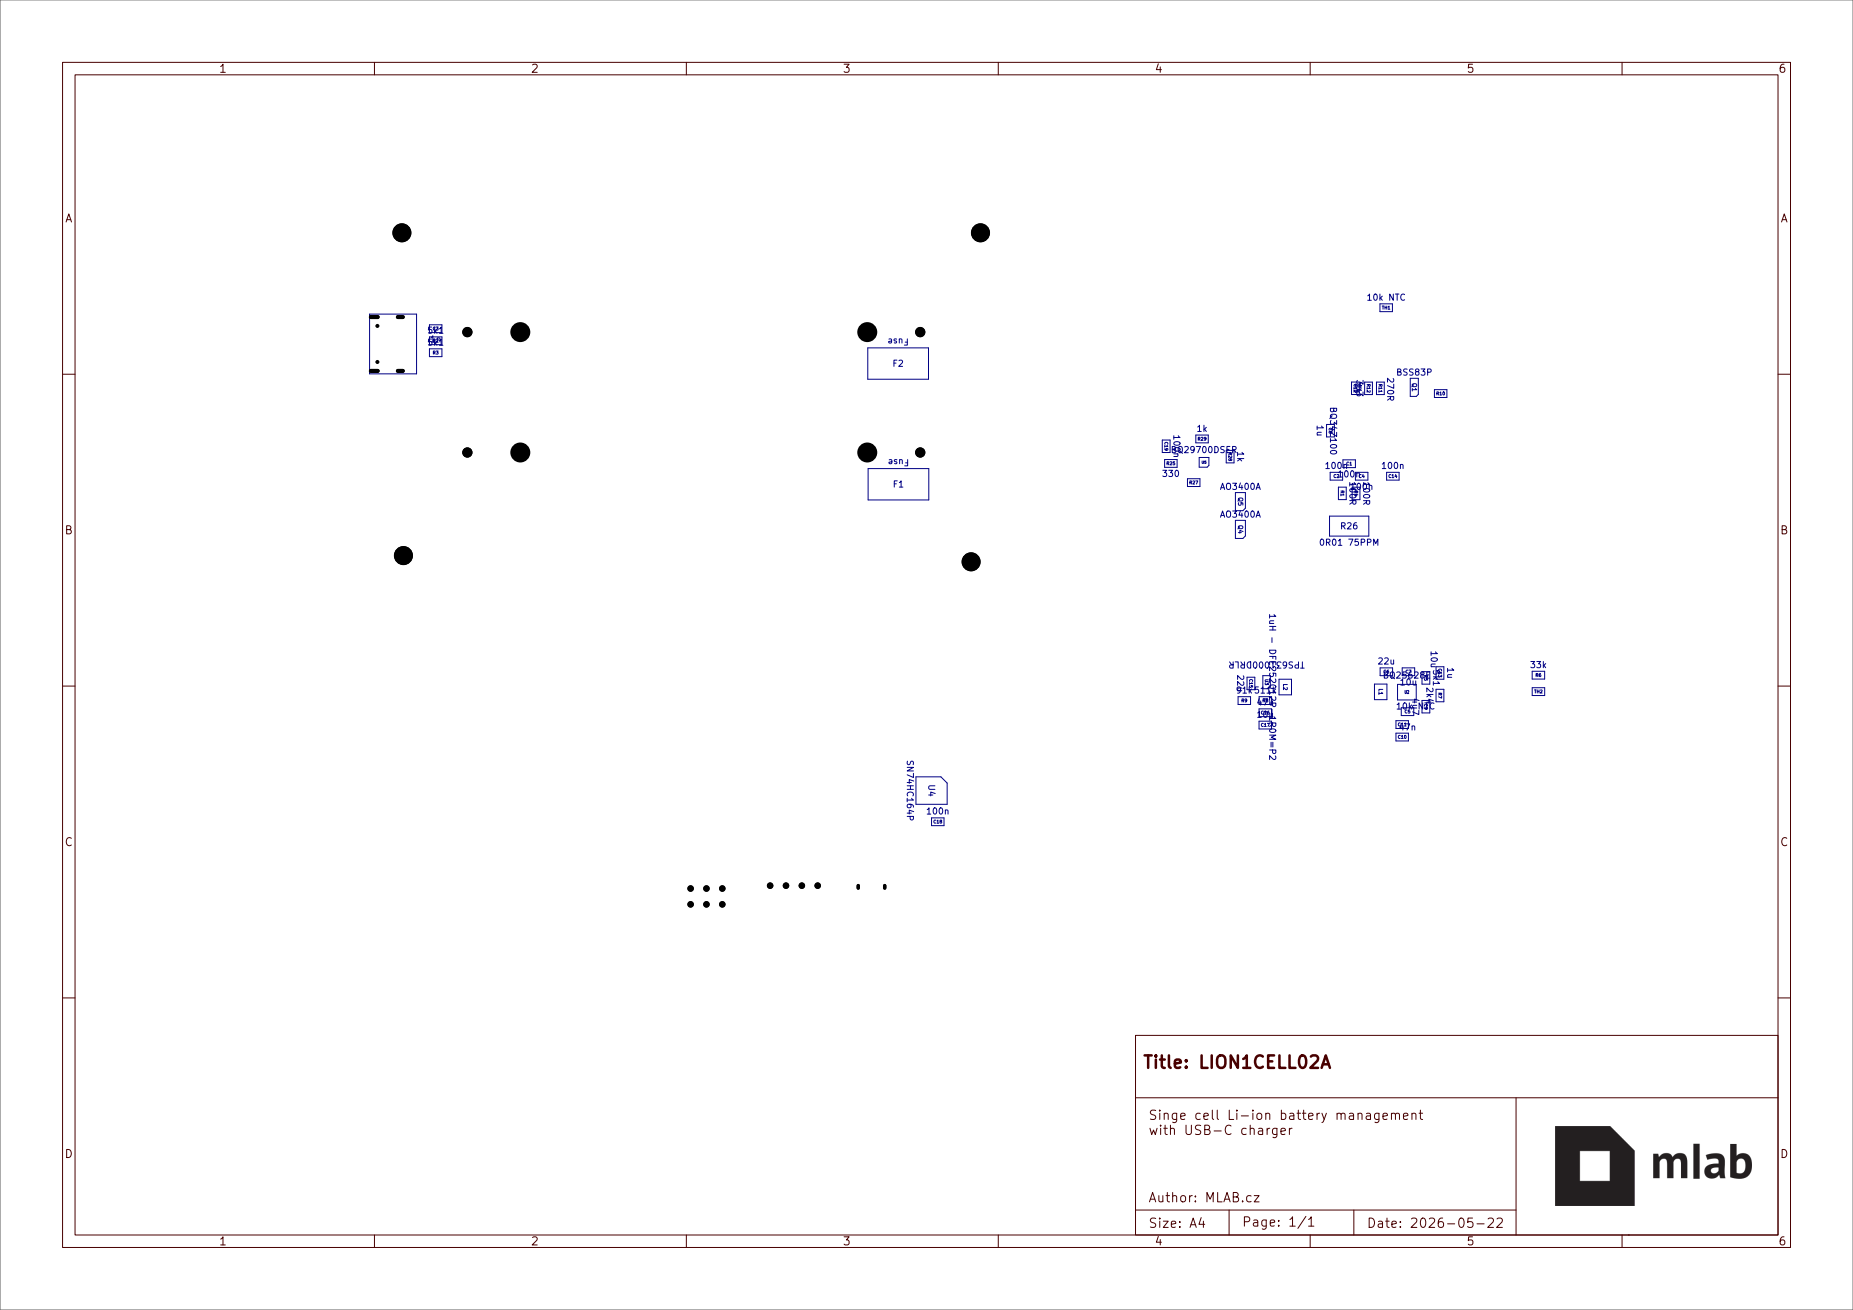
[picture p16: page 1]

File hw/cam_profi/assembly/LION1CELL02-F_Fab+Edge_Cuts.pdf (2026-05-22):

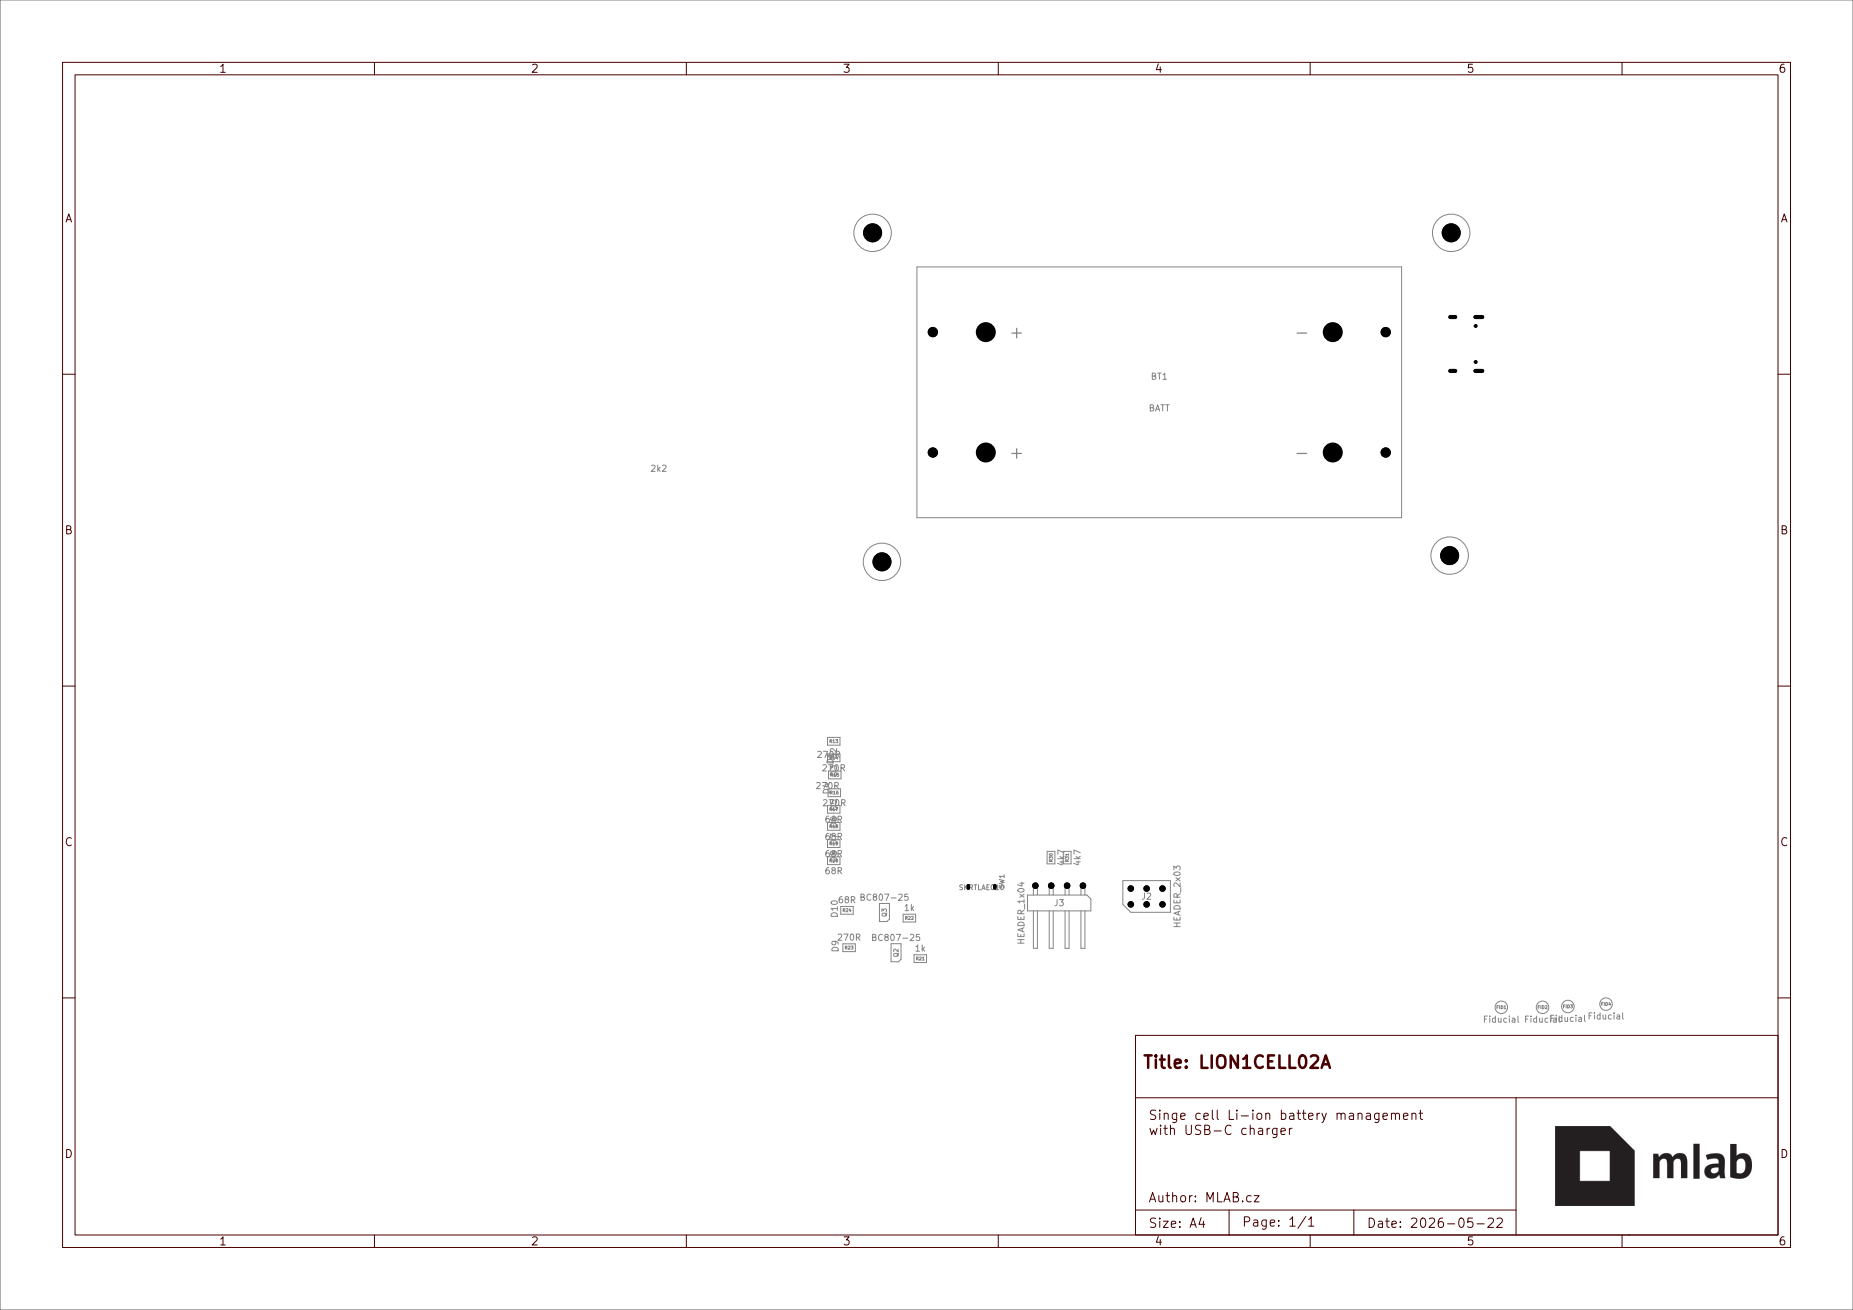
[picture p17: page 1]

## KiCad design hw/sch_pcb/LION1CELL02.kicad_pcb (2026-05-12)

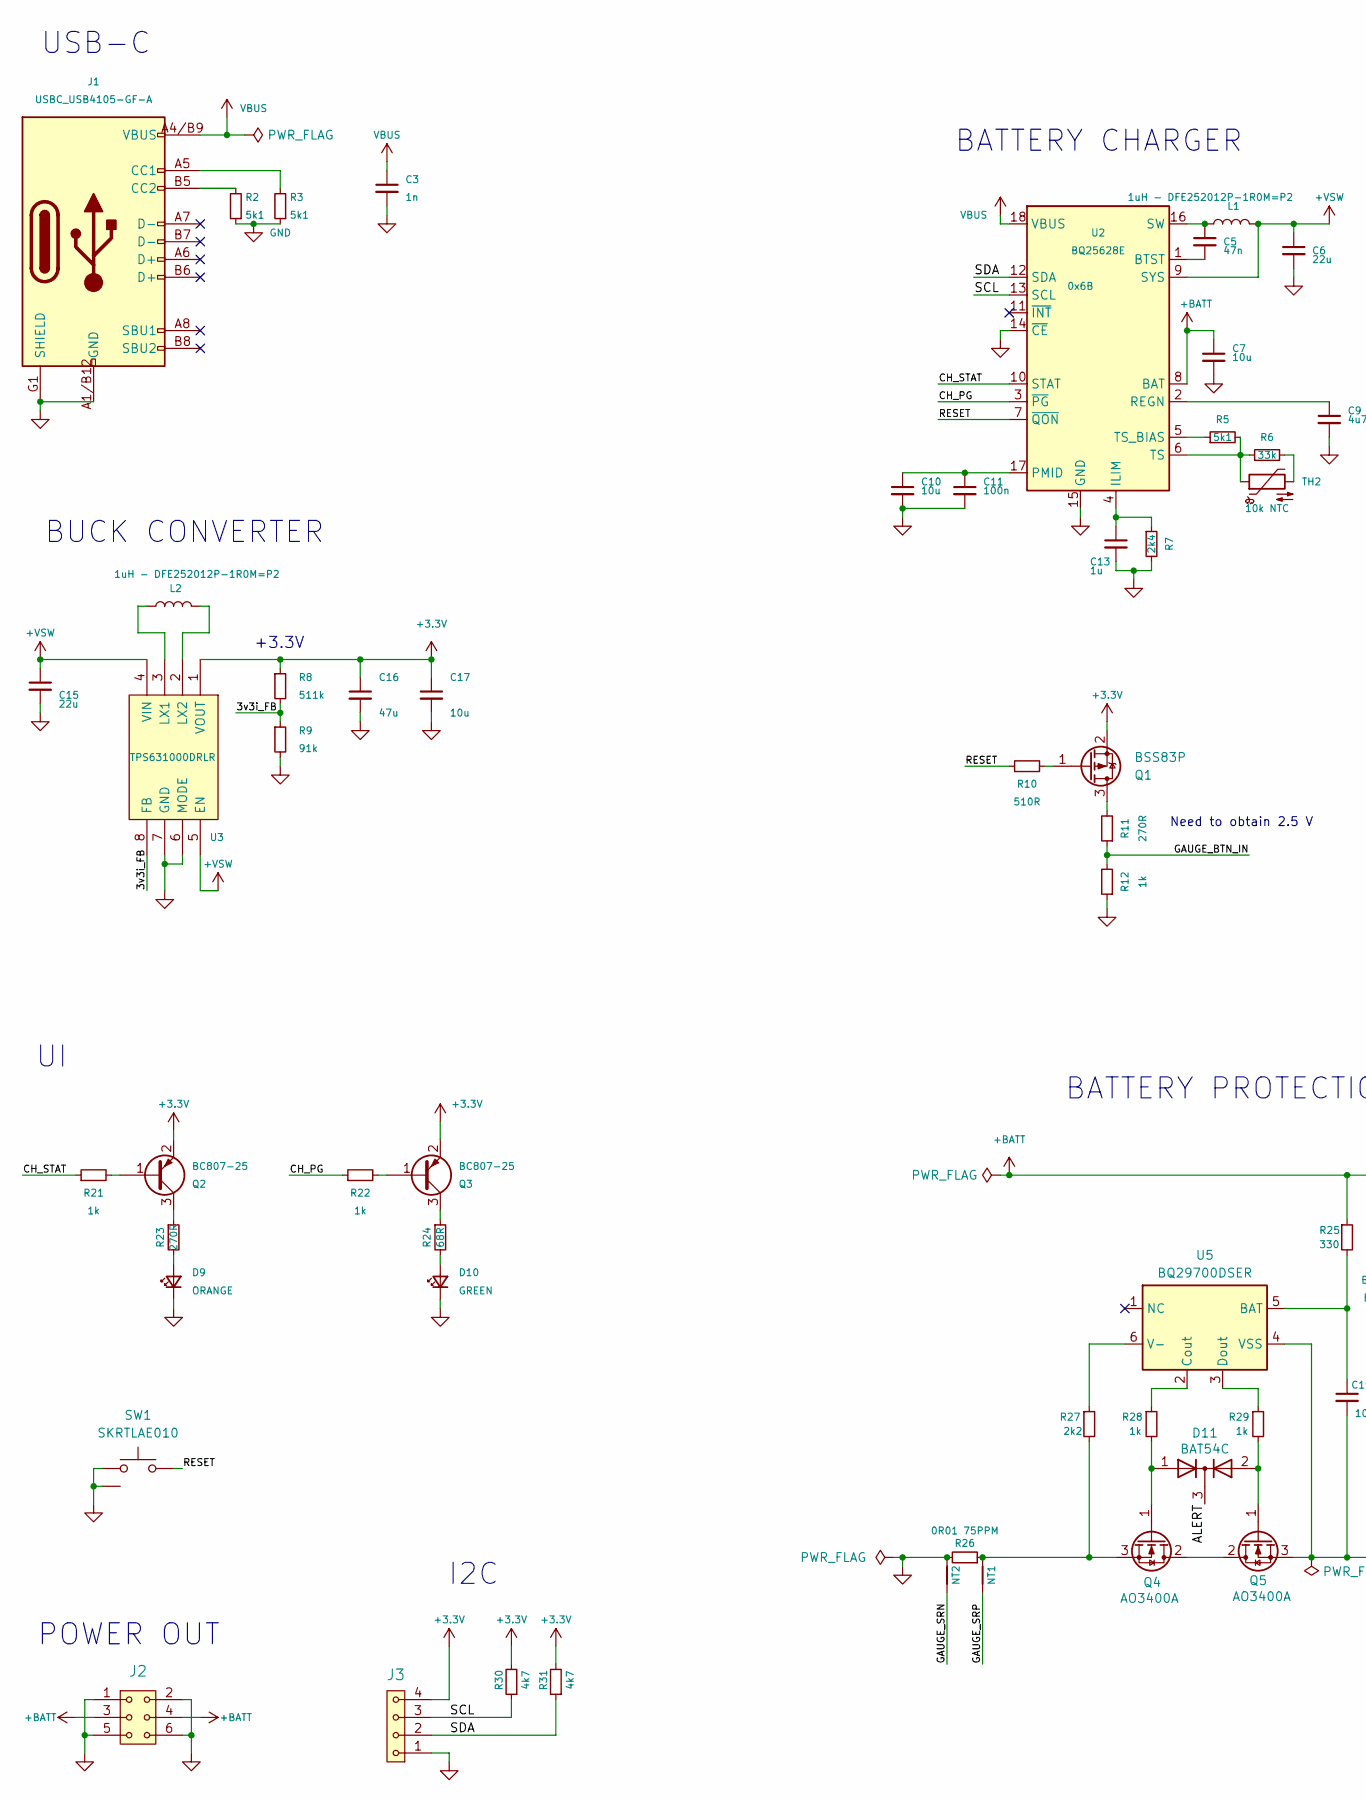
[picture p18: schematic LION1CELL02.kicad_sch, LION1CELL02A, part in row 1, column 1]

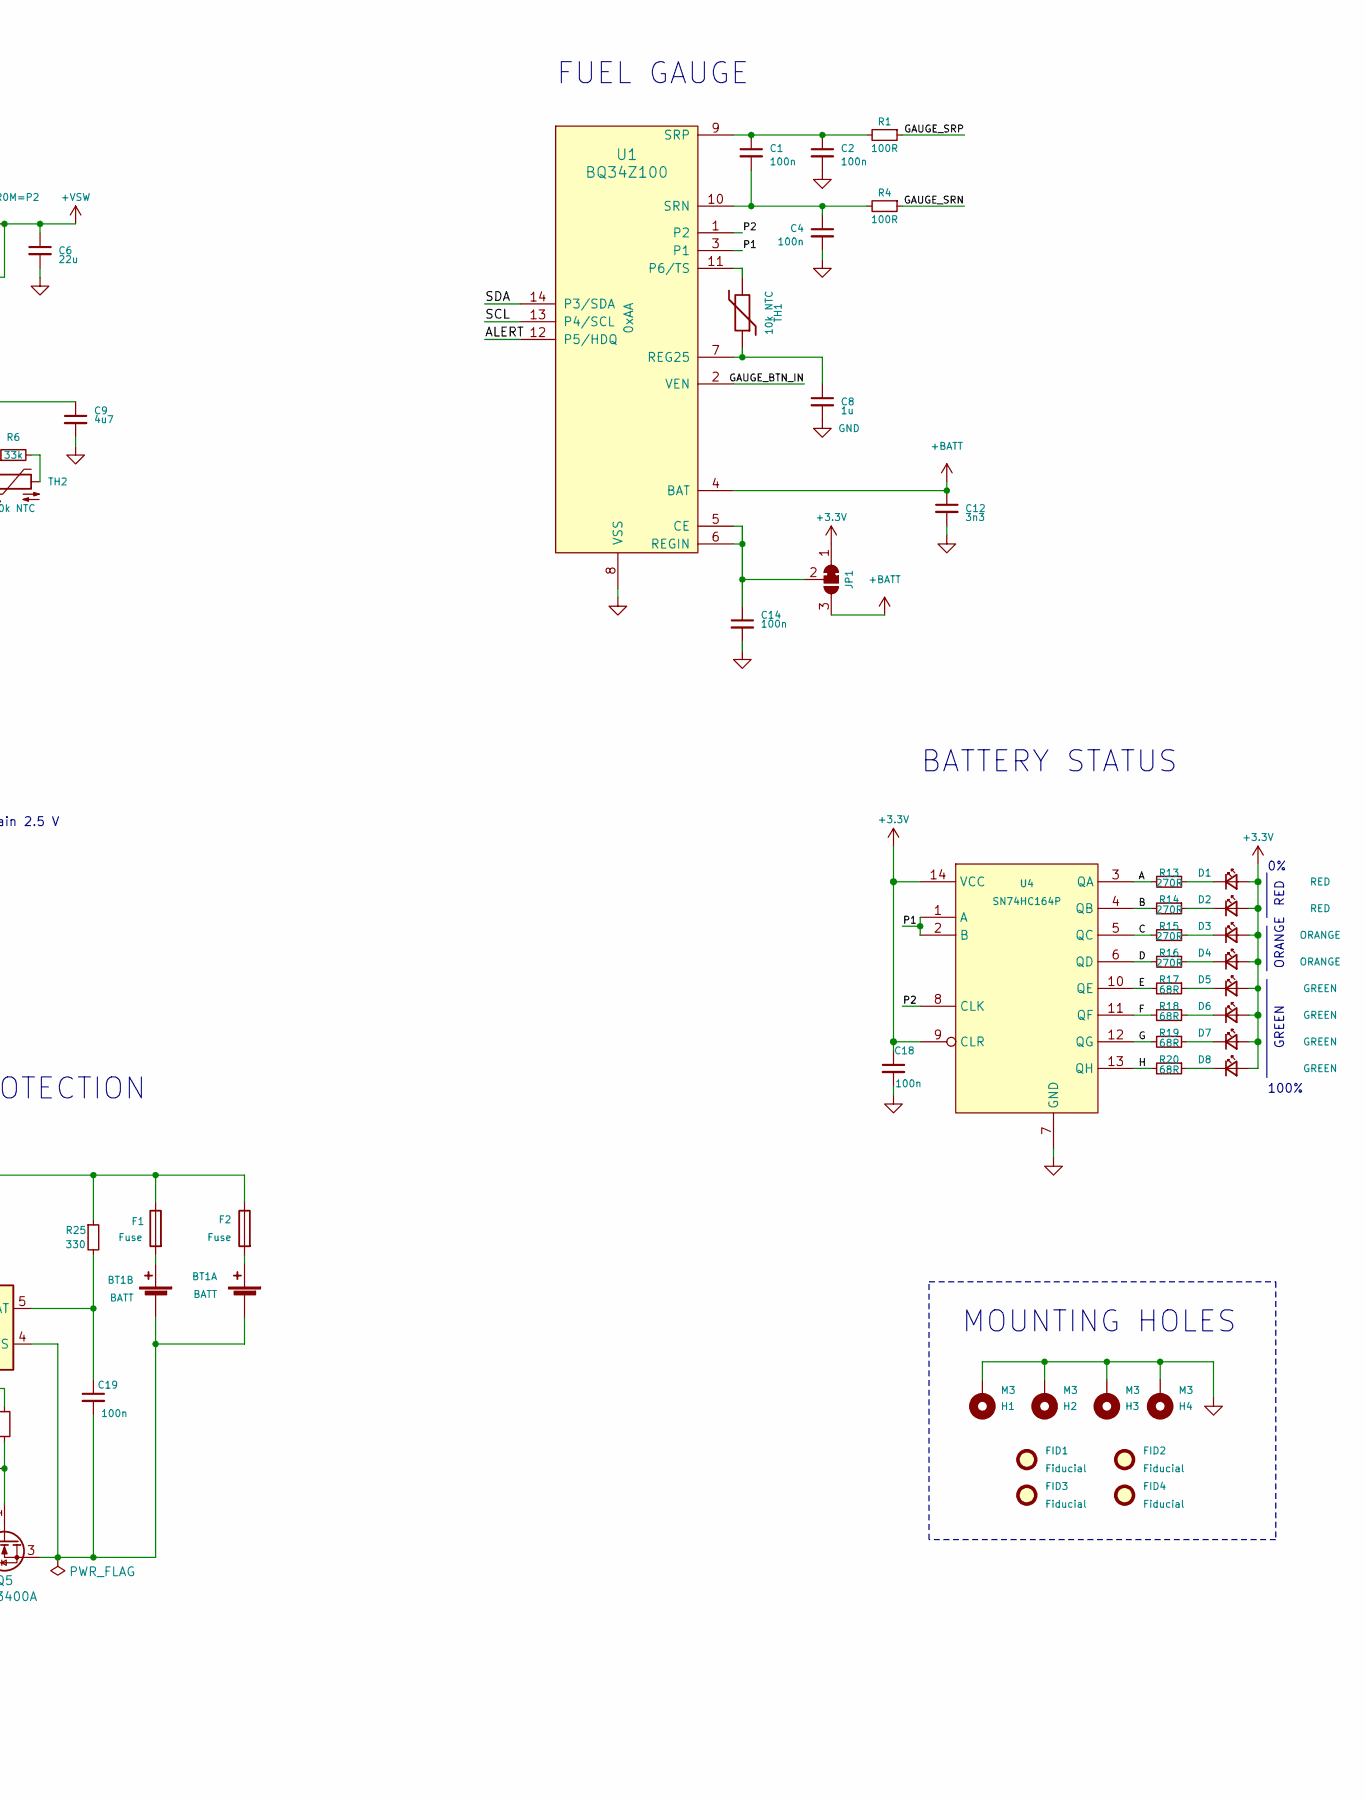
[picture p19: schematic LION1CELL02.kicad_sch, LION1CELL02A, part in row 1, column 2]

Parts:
BT1: BATT; BAT_BK-18650-PC4
C1, C2, C4, C11, C14, C18, C19: 100n; C_0805_2012Metric
C3: 1n; C_0805_2012Metric; MPN C0805 1u
C5: 47n; C_0805_2012Metric
C6, C15: 22u; C_0805_2012Metric
C7, C10, C17: 10u; C_0805_2012Metric
C8, C13: 1u; C_0805_2012Metric
C9: 4u7; C_0805_2012Metric
C12: 3n3; C_0805_2012Metric
C16: 47u; C_0805_2012Metric
D1, D2: RED; SMD_LED_RIGHT_KINGBRIGHT_1605
D3, D4, D9: ORANGE; SMD_LED_RIGHT_KINGBRIGHT_1605
D5, D6, D7, D8, D10: GREEN; SMD_LED_RIGHT_KINGBRIGHT_1605
D11: BAT54C; SOT-23
F1, F2: Fuse; Fuseholder_Littelfuse_Nano2_154x
FID1, FID2, FID3, FID4: Fiducial; Fiducial_1mm_Mask2mm
H1, H2, H3, H4: M3; MountingHole_3mm
J1: USBC_USB4105-GF-A; USBC GCT_USB4105-GF-A; MPN USB4105-GF-A
J2: HEADER_2x03; PinHeader_2x03_P2.54mm_Vertical
J3: HEADER_1x04; PinHeader_1x04_P2.54mm_Horizontal
JP1: Jumper_3_Bridged12; SolderJumper-3_P1.3mm_Bridged2Bar12_RoundedPad1.0x1.5mm
L1, L2: 1uH - DFE252012P-1R0M=P2; L_1008_2520Metric
NT1, NT2: NetTie_2; NetTie-2_SMD_Pad0.5mm
Q1: BSS83P; SOT-23
Q2, Q3: BC807-25; SOT-23-3
Q4, Q5: AO3400A; SOT-23-3
R1, R4: 100R; R_0805_2012Metric
R2, R3, R5: 5k1; R_0805_2012Metric
R6: 33k; R_0805_2012Metric
R7: 2k4; R_0805_2012Metric
R8: 511k; R_0805_2012Metric
R9: 91k; R_0805_2012Metric
R10: 510R; R_0805_2012Metric
R11, R13, R14, R15, R16, R23: 270R; R_0805_2012Metric
R12, R21, R22, R28, R29: 1k; R_0805_2012Metric
R17, R18, R19, R20, R24: 68R; R_0805_2012Metric
R25: 330; R_0805_2012Metric
R26: 0R01 75PPM; R_2512_6332Metric
R27: 2k2; R_0805_2012Metric
R30, R31: 4k7; R_0805_2012Metric
SW1: SKRTLAE010; SKRT
TH1, TH2: 10k NTC; R_0805_2012Metric
U1: BQ34Z100; TSSOP-14_4.4x5mm_Pitch0.65mm
U2: BQ25628E; Texas_S-WQFN-HR-18
U3: TPS631000DRLR; SOT-583-8; Mouser Part Number 595-TPS631000DRLR
U4: SN74HC164P; TSSOP-14_4.4x5mm_P0.65mm
U5: BQ29700DSER; WSON-6_1.5x1.5mm_P0.5mm

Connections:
+3.3V: C16.1, C17.1, C18.1, D1.2 (A), D2.2 (A), D3.2 (A), D4.2 (A), D5.2 (A), D6.2 (A), D7.2 (A), D8.2 (A), J3.4, JP1.1 (A), Q1.2 (S), Q2.2 (E), Q3.2 (E), R8.1, R30.2, R31.2, U3.1 (VOUT), U4.9 (CLR), U4.14 (VCC)
+BATT: C7.1, C12.1, F1.1, F2.1, J2.3, J2.4, JP1.3 (B), R25.1, U1.4 (BAT), U2.8 (BAT)
+VSW: C6.1, C15.1, L1.2, U2.9 (SYS), U3.4 (VIN), U3.5 (EN)
/3v3i_FB: R8.2, R9.1, U3.8 (FB)
/A: R13.2, U4.3 (QA)
/ALERT: D11.3 (K), U1.12 (P5/HDQ)
/B: R14.2, U4.4 (QB)
/C: R15.2, U4.5 (QC)
/CH_PG: R22.1, U2.3 (~PG)
/CH_STAT: R21.1, U2.10 (STAT)
/D: R16.2, U4.6 (QD)
/E: R17.2, U4.10 (QE)
/F: R18.2, U4.11 (QF)
/G: R19.2, U4.12 (QG)
/GAUGE_BTN_IN: R11.1, R12.2, U1.2 (VEN)
/GAUGE_SRN: NT2.1, R4.1
/GAUGE_SRP: NT1.1, R1.1
/H: R20.2, U4.13 (QH)
/P1: U1.3 (P1), U4.1 (A), U4.2 (B)
/P2: U1.1 (P2), U4.8 (CLK)
/RESET: R10.1, SW1.1, U2.7 (~QON)
/SCL: J3.3, R30.1, U1.13 (P4/SCL), U2.13 (SCL)
/SDA: J3.2, R31.1, U1.14 (P3/SDA), U2.12 (SDA)
GND: C2.2, C3.2, C4.2, C6.2, C7.2, C8.2, C9.2, C10.2, C11.2, C12.2, C13.2, C14.2, C15.2, C16.2, C17.2, C18.2, D9.1 (K), D10.1 (K), H1.1 (1_1), H2.1 (1_1), H3.1 (1_1), H4.1 (1_1), J1.A1/B12 (GND), J1.B1/A12 (GND), J1.G1 (SHIELD), J1.G2 (SHIELD), J1.G3 (SHIELD), J1.G4 (SHIELD), J2.1, J2.2, J2.5, J2.6, J3.1, NT2.2, R2.1, R3.1, R7.2, R9.2, R12.1, R26.2, SW1.2, SW1.GND (SHIELD), U1.8 (VSS), U2.14 (~CE), U2.15 (GND), U3.6 (MODE), U3.7 (GND), U4.7 (GND)
unnamed: BT1.1+ (+), F2.2
unnamed: BT1.1- (-), BT1.2- (-), C19.2, Q5.3 (S), U5.4 (VSS)
unnamed: BT1.2+ (+), F1.2
unnamed: D1.1 (K), R13.1
unnamed: D2.1 (K), R14.1
unnamed: D3.1 (K), R15.1
unnamed: D4.1 (K), R16.1
unnamed: D5.1 (K), R17.1
unnamed: D6.1 (K), R18.1
unnamed: D7.1 (K), R19.1
unnamed: D8.1 (K), R20.1
unnamed: D9.2 (A), R23.2
unnamed: D10.2 (A), R24.2
unnamed: J1.A5 (CC1), R3.2
unnamed: J1.B5 (CC2), R2.2
unnamed: C14.1, JP1.2 (C), U1.5 (CE), U1.6 (REGIN)
unnamed: Q1.3 (D), R11.2
unnamed: Q1.1 (G), R10.2
unnamed: Q2.1 (B), R21.2
unnamed: Q2.3 (C), R23.1
unnamed: Q3.1 (B), R22.2
unnamed: Q3.3 (C), R24.1
unnamed: Q4.2 (D), Q5.2 (D)
unnamed: D11.1 (A), Q4.1 (G), R28.2
unnamed: NT1.2, Q4.3 (S), R26.1, R27.2
unnamed: D11.2 (A), Q5.1 (G), R29.2
unnamed: R6.2, TH2.2
unnamed: TH1.2, U1.11 (P6/TS)
unnamed: C8.1, TH1.1, U1.7 (REG25)
unnamed: C1.2, C4.1, R4.2, U1.10 (SRN)
unnamed: C1.1, C2.1, R1.2, U1.9 (SRP)
unnamed: C5.2, U2.1 (BTST)
unnamed: C13.1, R7.1, U2.4 (ILIM)
unnamed: C10.1, C11.1, U2.17 (PMID)
unnamed: C9.1, U2.2 (REGN)
unnamed: C5.1, L1.1, U2.16 (SW)
unnamed: R5.2, R6.1, TH2.1, U2.6 (TS)
unnamed: R5.1, U2.5 (TS_BIAS)
unnamed: L2.1, U3.3 (LX1)
unnamed: L2.2, U3.2 (LX2)
unnamed: C19.1, R25.2, U5.5 (BAT)
unnamed: R28.1, U5.2 (Cout)
unnamed: R29.1, U5.3 (Dout)
unnamed: R27.1, U5.6 (V-)
VBUS: C3.1, J1.A4/B9 (VBUS), J1.B4/A9 (VBUS), U2.18 (VBUS)

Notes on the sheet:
+3.3V
BATTERY STATUS
POWER OUT
ORANGE
Need to obtain 2.5 V
I2C
BUCK CONVERTER
RED
100%
MOUNTING HOLES
USB-C
BATTERY PROTECTION
FUEL GAUGE
BATTERY CHARGER
GREEN

Board: 2 copper layers, 93 parts (55 on the bottom side), 69 nets, no tracks yet.

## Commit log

2023-04-13 schematics updated
    [LION1CELL02A.kicad_pcb, LION1CELL02A.kicad_sch, LION2CELL01D.kicad_pcb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]
2023-04-13 Update actions products
    [LION1CELL02A-B_Cu.gbr, LION1CELL02A-B_Mask.gbr, LION1CELL02A-B_Paste.gbr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]
2023-04-13 minor changes
    [LION1CELL02A.kicad_sch]
2023-07-05 automated commit; rename source files to new naming convence
    [LION1CELL02.kicad_pcb, LION1CELL02.kicad_sch]
2024-07-17 Update kicad project to version 8.
    [LION1CELL02.kicad_pcb, LION1CELL02.kicad_sch]
2025-11-30 Cleanup repository. Update project to KiCADv9.
    [LION1CELL02.kicad_pcb, LION1CELL02.kicad_sch]
2026-01-14 Update schematics
    [LION1CELL02.kicad_sch]
2026-01-16 Repository cleanup.
    [LION1CELL02.kicad_pcb, LION1CELL02.kicad_sch]
2026-01-17 Batery protection update
    [LION1CELL02.kicad_sch]
2026-01-17 Battery pack update
    [LION1CELL02.kicad_sch]
2026-01-17 Battery protection update
    [LION1CELL02.kicad_sch]
2026-01-17 Update pcb
    [LION1CELL02.kicad_sch]
2026-01-18 Update sch
    [LION1CELL02.kicad_pcb, LION1CELL02.kicad_sch]
2026-01-25 Pridani ochrany proti prehrati pres alert pin
    [LION1CELL02.kicad_pcb, LION1CELL02.kicad_sch]
2026-05-06 Move sensing resistor bellow protection transistors.
    [LION1CELL02.kicad_sch]
2026-05-15 Update workflow and submodule to KiCAD 10.
2026-05-15 Automatic update of KiCAD outputs
    [LION1CELL02-B_Adhesive.dxf, LION1CELL02-B_Courtyard.dxf, LION1CELL02-B_Cu.dxf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]
2026-05-22 Fix termistor unconnection https://github.com/mlab-modules/BATDATUNIT01/issues/16
    [LION1CELL02.kicad_sch]
